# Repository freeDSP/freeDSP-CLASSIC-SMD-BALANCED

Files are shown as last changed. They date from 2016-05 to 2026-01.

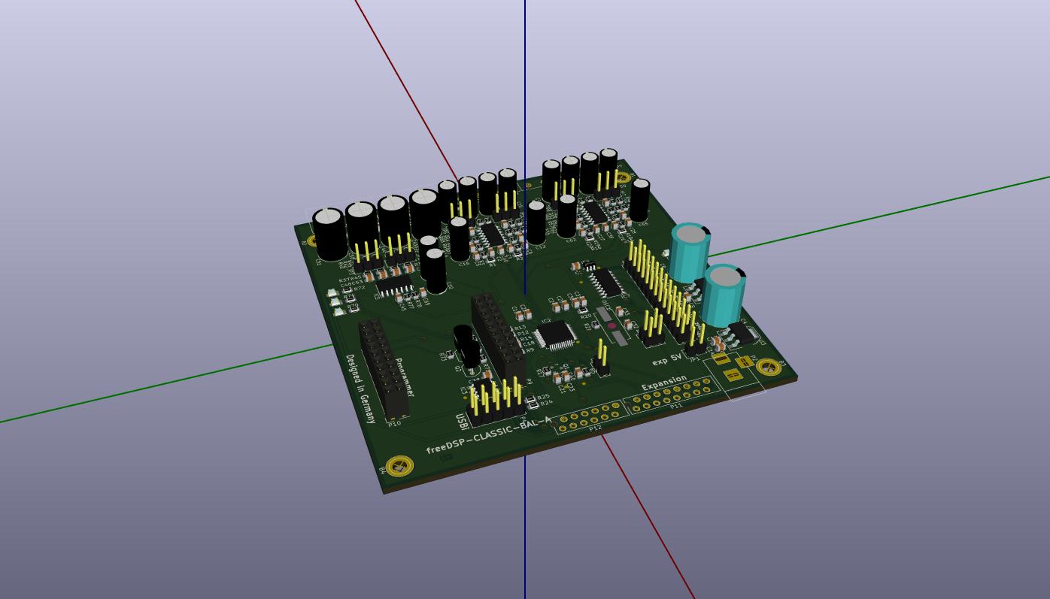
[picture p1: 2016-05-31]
DOCUMENTATION/PICTURES/rendering_betaversion.jpg

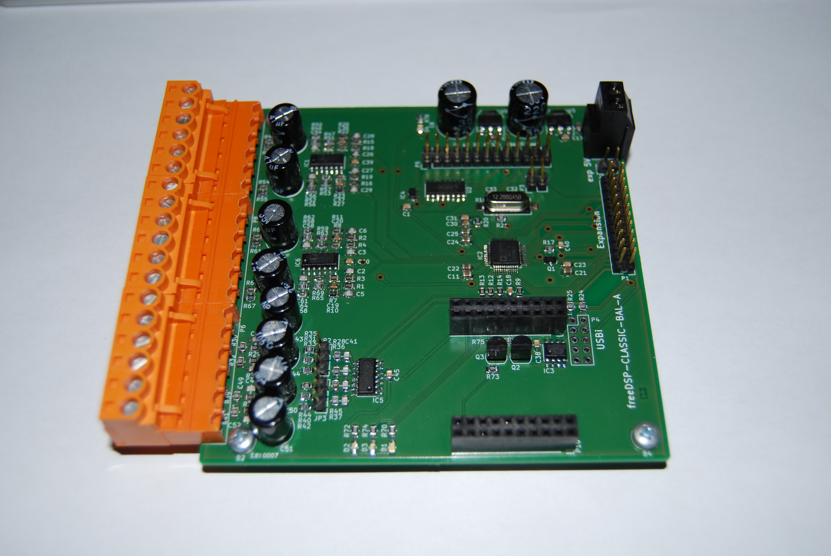
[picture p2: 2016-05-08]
DOCUMENTATION/PICTURES/DSC_0358.JPG

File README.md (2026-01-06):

# freeDSP-CLASSIC-SMD-BALANCED 
SMD Version with 1 I2S expansion header and balanced inputs/outputs and freeUSBi onboard.

## Upgrades from CLASSIC SMD A
- balanced audio inputs and outputs
- supports balanced interconnections with +6dBu (ARD nominal signal level)
- supports unbalanced interconnections with -10dBV (consumer audio nominal signal level)
- OpAmps supplied with +5V
- DC power input on barrel jack
- 1 standard I2S expansion header

For more information, please refer to the website [freedsp.github.io](https://freedsp.github.io/) and the documentation.  

## Status
Ready

## License

This work and all other materials under https://github.com/freeDSP are licensed under a <a rel="license" href="http://creativecommons.org/licenses/by-sa/4.0/legalcode">Creative Commons Attribution Share-Alike 4.0 license</a>. This allows for both personal and commercial derivative works, as long as they credit freeDSP and release their designs under the same license.

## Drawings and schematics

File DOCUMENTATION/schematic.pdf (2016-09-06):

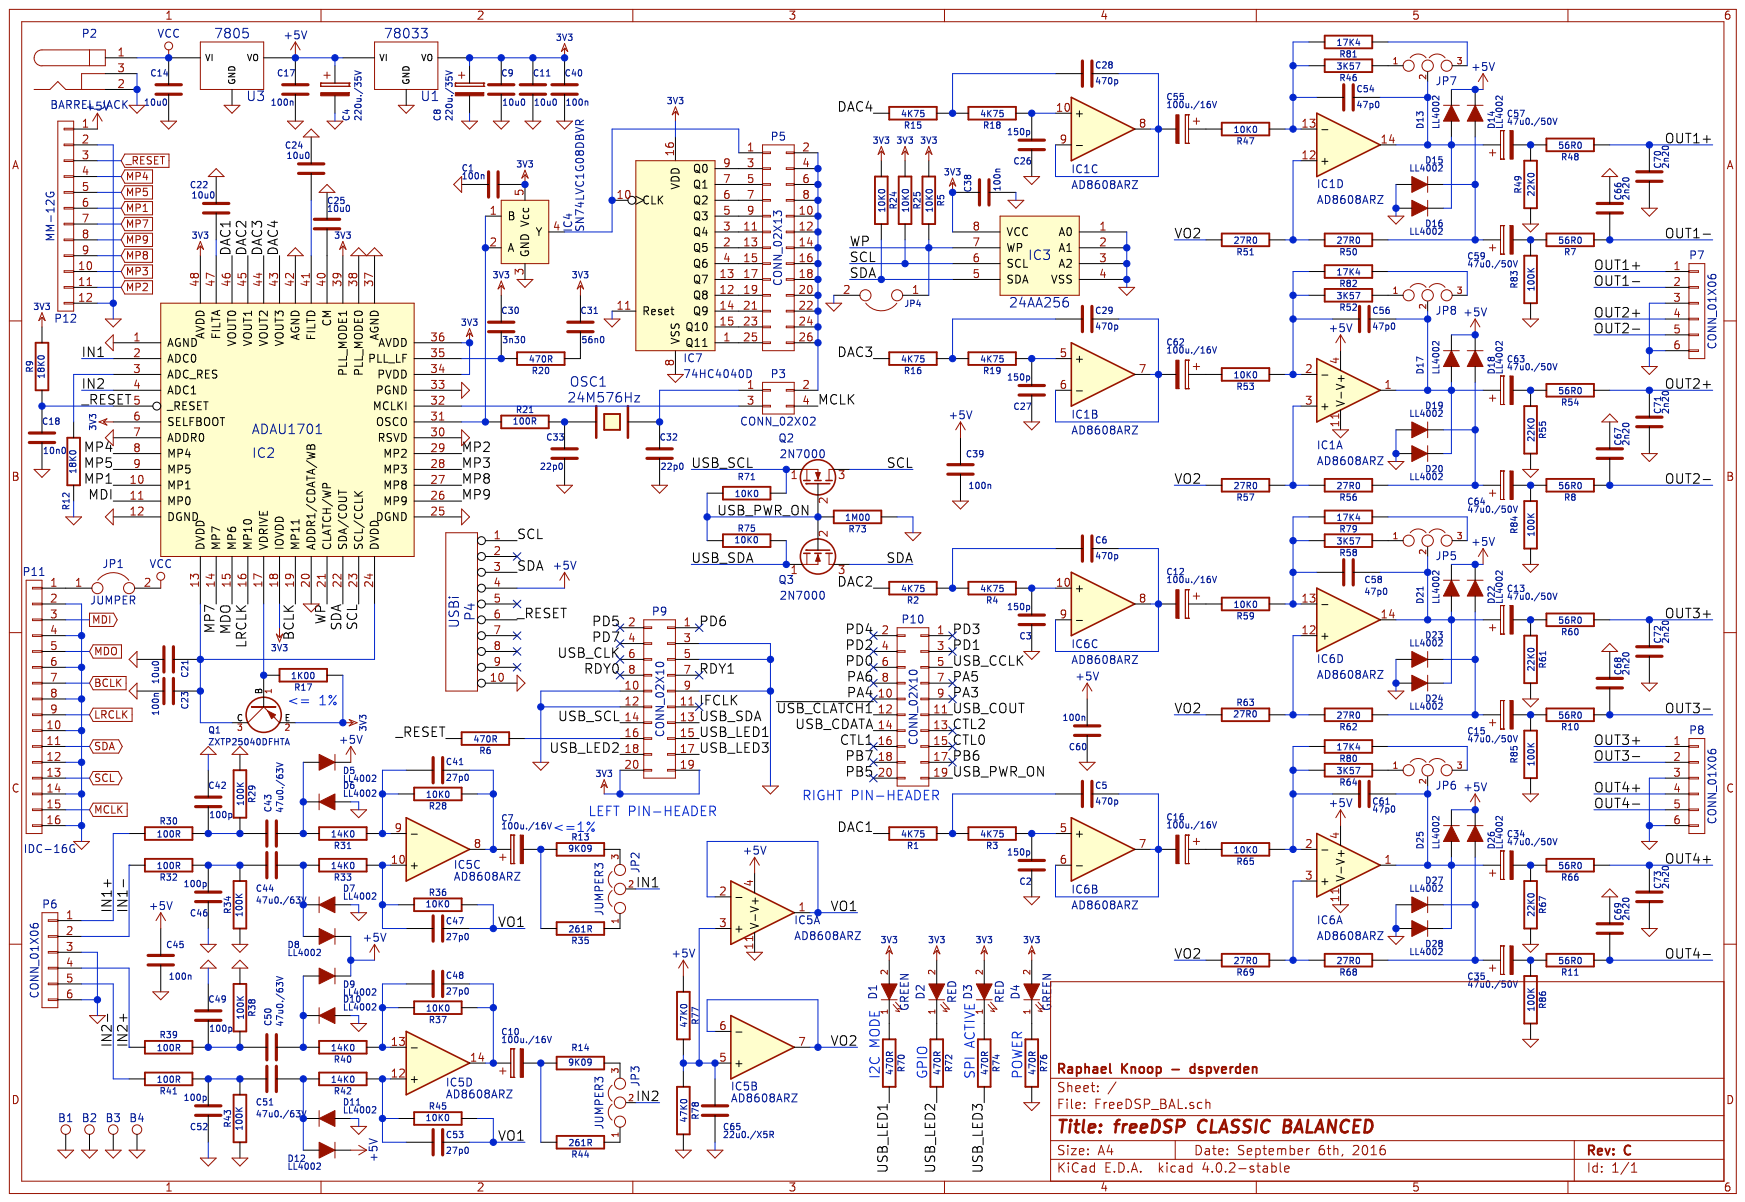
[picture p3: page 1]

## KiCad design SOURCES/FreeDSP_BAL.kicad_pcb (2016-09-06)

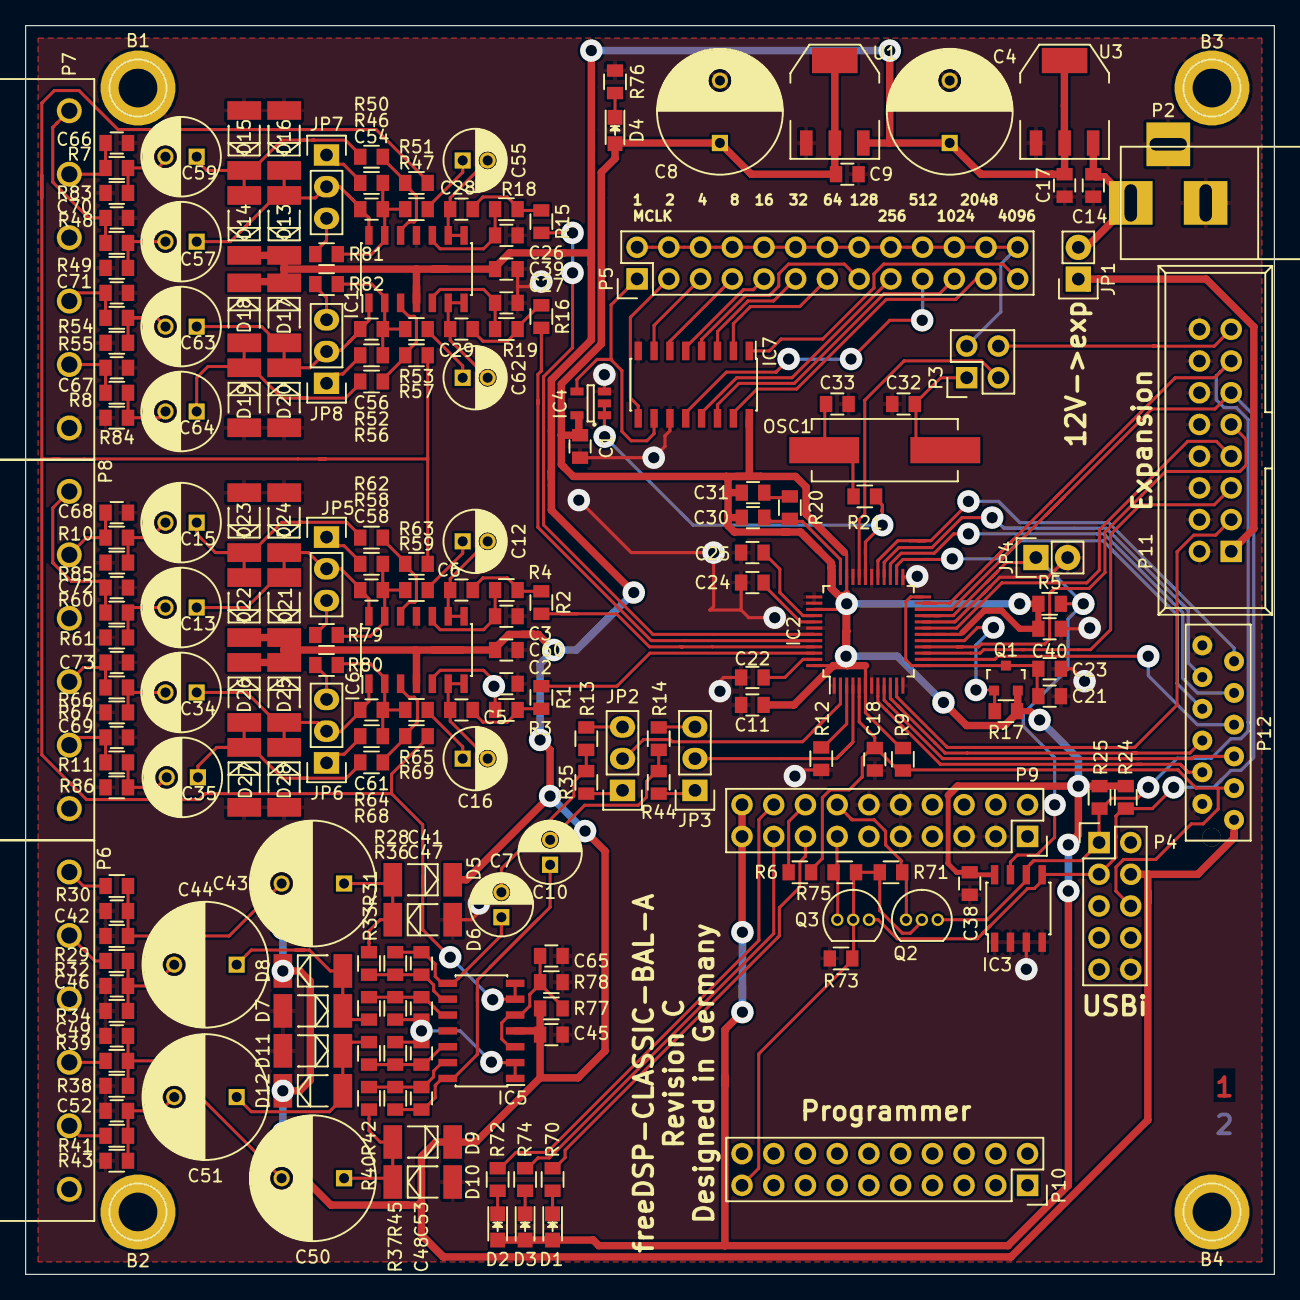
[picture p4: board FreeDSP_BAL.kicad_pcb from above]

Board: 2 copper layers, 100.0 x 100.0 mm, 215 parts (0 on the bottom side), 148 nets.

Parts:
B1, B2, B3, B4: TEST_1P; 1pin
C1, C17, C23, C38, C39, C40, C45, C60: 100n; C0805-X7R
C2, C3, C26, C27: 150p; C0805-X7R
C4, C8: 220u./35V; C_Radial_D10_L13_P5
C5, C6, C28, C29: 470p; C0805-X7R
C7, C10, C12, C16, C55, C62: 100u./16V; C_Radial_D5_L11_P2
C9, C11, C14, C21, C22, C24, C25: 10u0; C0805-X7R
C13, C15, C34, C35, C57, C59, C63, C64: 47u0./50V; C_Radial_D6.3_L11.2_P2.5
C18: 10n0; C0805-X7R
C30: 3n30; C0805-X7R
C31: 56n0; C0805-X7R
C32, C33: 22p0; C0805-X7R
C41, C47, C48, C53: 27p0; C0805-X7R
C42, C46, C49, C52: 100p; C0805-X7R
C43, C44, C50, C51: 47u0./63V; C_Radial_D10_L16_P5
C54, C56, C58, C61: 47p0; C0805-X7R
C65: 22u0./X5R; C0805-X7R
C66, C67, C68, C69, C70, C71, C72, C73: 2n20; C0805-X7R
D1, D4: GREEN; LED_0805
D2, D3: RED; LED_0805
D5, D6, D7, D8, D9, D10, D11, D12, D13, D14, D15, D16, D17, D18, D19, D20, D21, D22, D23, D24, D25, D26, D27, D28: LL4002; MELF_Standard
IC1, IC5, IC6: AD8608ARZ; SOIC-14_3.9x8.7mm_Pitch1.27mm
IC2: ADAU1701; LQFP-48_7x7mm_Pitch0.5mm
IC3: 24AA256; SOIC-8_3.9x4.9mm_Pitch1.27mm
IC4: SN74LVC1G08DBVR; SOT-23-5
IC7: 74HC4040D; SOIC-16_3.9x9.9mm_Pitch1.27mm
JP1, JP4: JUMPER; Pin_Header_Straight_1x02
JP2, JP3, JP5, JP6, JP7, JP8: JUMPER3; Pin_Header_Straight_1x03
OSC1: 24M576Hz; Crystal_HC49-SD_SMD
P2: BARREL_JACK
P3: CONN_02X02; Pin_Header_Straight_2x02
P4: USBi; Pin_Header_Straight_2x05
P5: CONN_02X13; Pin_Header_Straight_2x13
P6, P7, P8: CONN_01X06; SL_5.08HC-06-90
P9, P10: CONN_02X10; Socket_Strip_Straight_2x10
P11: IDC-16G; IDC_Header_Straight_16pins
P12: MM-12G
Q1: ZXTP25040DFHTA; SOT-23
Q2, Q3: 2N7000; TO-92_Inline_Narrow_Oval
R1, R2, R3, R4, R15, R16, R18, R19: 4K75; C0805-RES
R5, R24, R25, R28, R36, R37, R45, R47, R53, R59, R65, R71, R75: 10K0; C0805-RES
R6, R20, R70, R72, R74, R76: 470R; C0805-RES
R7, R8, R10, R11, R48, R54, R60, R66: 56R0; C0805-RES
R9, R12: 18K0; C0805-RES
R13, R14: 9K09; C0805-RES
R17: 1K00; C0805-RES
R21, R30, R32, R39, R41: 100R; C0805-RES
R29, R34, R38, R43, R83, R84, R85, R86: 100K; C0805-RES
R31, R33, R40, R42: 14K0; C0805-RES
R35, R44: 261R; C0805-RES
R46, R52, R58, R64: 3K57; C0805-RES
R49, R55, R61, R67: 22K0; C0805-RES
R50, R51, R56, R57, R62, R63, R68, R69: 27R0; C0805-RES
R73: 1M00; C0805-RES
R77, R78: 47K0; C0805-RES
R79, R80, R81, R82: 17K4; C0805-RES
U1: 78033; SOT-223_Reg_MAE
U3: 7805; SOT-223_Reg_MAE

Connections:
3V3: C1.1, C8.1, C9.1, C11.1, C30.1, C31.1, C38.1, C40.1, D1.2, D2.2, D3.2, D4.2, IC2.6, IC2.18, IC2.34, IC2.36, IC2.39, IC2.48, IC3.8, IC4.5, IC7.16, P9.19, P9.20, Q1.2, R5.2, R9.2, R17.2, R24.2, R25.2, U1.VO
+5V: C4.1, C17.1, C39.2, C45.2, C60.2, D5.1, D8.1, D9.1, D12.1, D13.1, D14.1, D17.1, D18.1, D21.1, D22.1, D25.1, D26.1, IC1.4, IC5.4, IC6.4, P4.4, P12.1, R77.1, U1.VI, U3.VO
/DAC1: IC2.46, R1.2
/DAC2: IC2.45, R2.2
/DAC3: IC2.44, R16.2
/DAC4: IC2.43, R15.2
/IN1: IC2.2, JP2.2
/IN1+: P6.1, R30.2
/IN1-: P6.2, R32.2
/IN2: IC2.4, JP3.2
/IN2+: P6.4, R39.2
/IN2-: P6.5, R41.2
/OUT1+: C70.2, P7.1, R48.1
/OUT1-: C66.1, P7.2, R7.1
/OUT2+: C71.2, P7.4, R54.1
/OUT2-: C67.1, P7.5, R8.1
/OUT3+: C72.2, P8.1, R60.1
/OUT3-: C68.1, P8.2, R10.1
/OUT4+: C73.2, P8.4, R66.1
/OUT4-: C69.1, P8.5, R11.1
/USB_LED1: P9.15, R70.2
/USB_LED2: P9.18, R72.2
/USB_LED3: P9.17, R74.2
/USB_PWR_ON: P10.19, Q2.2, Q3.2, R71.2, R73.2, R75.1
/USB_SCL: P9.14, Q2.1, R71.1
/USB_SDA: P9.13, Q3.1, R75.2
/VO1: C47.2, C53.2, IC5.1, IC5.2, R36.2, R45.2
/VO2: IC5.6, IC5.7, R51.2, R57.2, R63.1, R69.2
/WP: IC2.21, IC3.7, JP4.1, R5.1
BCLK: IC2.19, P11.7
GND: B1.1, B2.1, B3.1, B4.1, C1.2, C2.1, C3.1, C4.2, C8.2, C9.2, C11.2, C14.2, C17.2, C18.2, C21.2, C22.2, C23.2, C24.2, C25.2, C26.1, C27.1, C32.2, C33.2, C38.2, C39.1, C40.2, C42.1, C45.1, C46.1, C49.1, C52.1, C60.1, C65.1, C66.2, C67.2, C68.2, C69.2, C70.1, C71.1, C72.1, C73.1, D6.2, D7.2, D10.2, D11.2, D15.2, D16.2, D19.2, D20.2, D23.2, D24.2, D27.2, D28.2, IC1.11, IC2.1, IC2.7, IC2.12, IC2.20, IC2.25, IC2.30, IC2.33, IC2.37, IC2.38, IC2.42, IC3.1, IC3.2, IC3.3, IC3.4, IC4.3, IC5.11, IC6.11, IC7.8, IC7.11, JP4.2, P2.2, P2.3, P4.10, P6.3, P6.6, P7.3, P7.6, P8.3, P8.6, P9.3, P9.5, P9.9, P9.10, P9.12, P11.2, P11.4, P11.6, P11.8, P11.10, P11.12, P11.14, P11.16, P12.2, P12.12, R12.1, R29.1, R34.1, R38.1, R43.1, R49.2, R55.2, R61.2, R67.2, R73.1, R76.2, R78.2, R83.2, R84.2, R85.2, R86.2, U1.GND, U3.GND
LRCLK: IC2.16, P11.9
MCLK: P3.4, P11.15
MDI: IC2.11, P11.3
MDO: IC2.15, P11.5
MP1: IC2.10, P12.6
MP2: IC2.29, P12.11
MP3: IC2.28, P12.10
MP4: IC2.8, P12.4
MP5: IC2.9, P12.5
MP7: IC2.14, P12.7
MP8: IC2.27, P12.9
MP9: IC2.26, P12.8
unnamed: C2.2, IC6.5, R3.1
unnamed: C3.2, IC6.10, R4.1
unnamed: C5.2, R1.1, R3.2
unnamed: C6.2, R2.1, R4.2
unnamed: C7.2, R13.1, R35.2
unnamed: C10.1, C48.1, IC5.14, R37.1
unnamed: C10.2, R14.1, R44.2
unnamed: C12.1, R59.2
unnamed: C6.1, C12.2, IC6.8, IC6.9
unnamed: C13.1, C58.1, D21.2, D24.1, IC6.14, JP5.2
unnamed: C13.2, R60.2, R61.1
unnamed: C15.1, D22.2, D23.1, R62.1
unnamed: C15.2, R10.2, R85.1
unnamed: C16.1, R65.2
unnamed: C5.1, C16.2, IC6.6, IC6.7
unnamed: C21.1, C23.1, IC2.13, IC2.24, Q1.3
unnamed: C22.1, IC2.47
unnamed: C24.1, IC2.41
unnamed: C25.1, IC2.40
unnamed: C26.2, IC1.10, R18.1
unnamed: C27.2, IC1.5, R19.1
unnamed: C28.1, C55.2, IC1.8, IC1.9
unnamed: C28.2, R15.1, R18.2
unnamed: C29.1, C62.2, IC1.6, IC1.7
unnamed: C29.2, R16.1, R19.2
unnamed: C30.2, IC2.35, R20.2
unnamed: C31.2, R20.1
unnamed: C32.1, OSC1.2, P3.1
unnamed: C33.1, OSC1.1, R21.2
unnamed: C34.1, C61.1, D25.2, D28.1, IC6.1, JP6.2
unnamed: C34.2, R66.2, R67.1
unnamed: C35.1, D26.2, D27.1, R68.1
unnamed: C35.2, R11.2, R86.1
unnamed: C7.1, C41.1, IC5.8, R28.1
unnamed: C41.2, IC5.9, R28.2, R31.1
unnamed: C42.2, C43.2, R29.2, R30.1
unnamed: C43.1, D5.2, D6.1, R31.2
unnamed: C44.1, D7.1, D8.2, R33.2
unnamed: C44.2, C46.2, R32.1, R34.2
unnamed: C47.1, IC5.10, R33.1, R36.1
unnamed: C48.2, IC5.13, R37.2, R40.1
unnamed: C49.2, C50.2, R38.2, R39.1
unnamed: C50.1, D9.2, D10.1, R40.2
unnamed: C51.1, D11.1, D12.2, R42.2
unnamed: C51.2, C52.2, R41.1, R43.2
unnamed: C53.1, IC5.12, R42.1, R45.1
unnamed: C54.1, C57.1, D13.2, D16.1, IC1.14, JP7.2
unnamed: C54.2, IC1.13, R46.2, R47.1, R81.2
unnamed: C55.1, R47.2
unnamed: C56.1, C63.1, D17.2, D20.1, IC1.1, JP8.2
unnamed: C56.2, IC1.2, R52.2, R53.1, R82.2
unnamed: C57.2, R48.2, R49.1
unnamed: C58.2, IC6.13, R58.2, R59.1, R79.2
unnamed: C59.1, D14.2, D15.1, R50.1
unnamed: C59.2, R7.2, R83.1
unnamed: C61.2, IC6.2, R64.2, R65.1, R80.2
unnamed: C62.1, R53.2
unnamed: C63.2, R54.2, R55.1
unnamed: C64.1, D18.2, D19.1, R56.1
unnamed: C64.2, R8.2, R84.1
unnamed: C65.2, IC5.3, IC5.5, R77.2, R78.1
unnamed: D1.1, R70.1
unnamed: D2.1, R72.1
unnamed: D3.1, R74.1
unnamed: D4.1, R76.1
unnamed: IC1.3, R56.2, R57.1
unnamed: IC1.12, R50.2, R51.1
unnamed: IC2.3, R12.2
unnamed: IC2.17, Q1.1, R17.1
unnamed: IC2.31, IC4.1, IC4.2, R21.1
unnamed: IC2.32, P3.3
unnamed: IC4.4, IC7.10, P5.1
unnamed: IC6.3, R68.2, R69.1
unnamed: IC6.12, R62.2, R63.2
unnamed: IC7.1, P5.25
unnamed: IC7.2, P5.13
unnamed: IC7.3, P5.11
unnamed: IC7.4, P5.15
unnamed: IC7.5, P5.9
unnamed: IC7.6, P5.7
unnamed: IC7.7, P5.5
unnamed: IC7.9, P5.3
unnamed: IC7.12, P5.19
unnamed: IC7.13, P5.17
unnamed: IC7.14, P5.21
unnamed: IC7.15, P5.23
unnamed: JP1.1, P11.1
unnamed: JP2.1, R35.1
unnamed: JP2.3, R13.2
unnamed: JP3.1, R44.1
unnamed: JP3.3, R14.2
unnamed: JP5.1, R58.1
unnamed: JP5.3, R79.1
unnamed: JP6.1, R64.1
unnamed: JP6.3, R80.1
unnamed: JP7.1, R46.1
unnamed: JP7.3, R81.1
unnamed: JP8.1, R52.1
unnamed: JP8.3, R82.1
unnamed: P3.2, P5.2, P5.4, P5.6, P5.8, P5.10, P5.12, P5.14, P5.16, P5.18, P5.20, P5.22, P5.24, P5.26
unnamed: P9.16, R6.1
SCL: IC2.23, IC3.6, P4.1, P11.13, Q2.3, R25.1
SDA: IC2.22, IC3.5, P4.3, P11.11, Q3.3, R24.1
VCC: C14.1, JP1.2, P2.1, U3.VI
_RESET: C18.1, IC2.5, P4.6, P12.3, R6.2, R9.1

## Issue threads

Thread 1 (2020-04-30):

PCB Updated with 3d packages

mbt28, 2020-04-30:
Hi,

I updated the pcb with built-in 3d packages of KiCAD. All the units have their 3d shapes beside P2 Power Barrel Jack and P12. You can find the rendered images below. If you are interested in to update the github source I can share the files.

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

Have a nice day

BasssT, 2020-05-04:
Very nice. Thanks. I give you rights to update the repo if you like.

Closed 2020-05-04.

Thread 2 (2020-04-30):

Full SMD packages

mbt28, 2020-04-30:
Hi,

I am not audio expert thats why I am asking, are there any reason that you are using some of the caps are tht? If it is possible we can order the whole pcb prototype from cheap manufacturers.

If yes I will try to find smd compenent parts for replacement.

Thanks

BasssT, 2020-05-04:
You can replace everything with smd components if available. Please share if you found a producer. Thanks.

mbt28, 2020-05-06:
Hi,

I started to replace some of the TH parts already however the capacitors: C43, C44, C50, C51 seems like to have value 47u0./63V, does it mean 47uf 6.3V or 63V?

Thanks

dspverden, 2020-05-06:
Hi,

the caps are tht because I had them in stock. They are rated at 63V.  You can replace them by e.g. 25V. Please make sure that you use bipolar electrolytic caps or orient the caps in the right way: There is positive voltage offset on the opamp side.

Raphael

mbt28, 2020-05-07:
Hi Again,

Finally I replaced all the components(beside connectors) with the SMD ones but I need to fix the routes as well. What kind of connector is P12? Do you have any link to the datasheet? I cannot find a similar connector in KiCAD.

Thanks

So far looks like something this:
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

dspverden, 2020-05-10:
P12 is a MicroMatch from TE. You can easily find the 3D model for it.[https://www.te.com/deu-de/product-8-215079-2.html](url)

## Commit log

2016-05-08 Picture of prototype.
2016-05-12 Cleaned BOM (footprints).
    [FreeDSP_SMD.kicad_pcb, FreeDSP_SMD.sch]
2016-05-17 - Added 10K PullUp and GND-Jumper on WP-line - Fixed footprint of Q1
    [FreeDSP_SMD.kicad_pcb, FreeDSP_SMD.sch]
2016-05-19 - Bugfix ADC-Stage: Applied VCC/2 - Changed VCC of OpAmps to +5V - Changed gains, Pro: +6dBu (ARD-Norm) and Con: -10dBv for full scale
    [FreeDSP_SMD.kicad_pcb, FreeDSP_SMD.sch]
2016-05-20 Bugfix DAC-Stage: Applied VCC/2 - Supplied OpAmps with +5V - Reworked gain settings: Pro +6dBu, Consumer -10dBV
    [FreeDSP_SMD.kicad_pcb, FreeDSP_SMD.sch]
2016-05-21 Changed DC supply connector to barrel jack
    [FreeDSP_SMD.kicad_pcb, FreeDSP_SMD.sch]
2016-05-23 Moved EZ-USB sockets => EZ-USB now fits into standard enclosure.
    [FreeDSP_SMD.kicad_pcb]
2016-05-24 Changed expansion header to new standard i2s expansion header
    [FreeDSP_SMD.kicad_pcb, FreeDSP_SMD.sch]
2016-05-24 WB on GND
    [FreeDSP_SMD.kicad_pcb, FreeDSP_SMD.sch]
2016-05-29 Updated Gerber and BOM
    [FreeDSP_BAL.kicad_pcb, FreeDSP_BAL.sch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]
2016-05-31 Added 3D rendering of beta-Ready version.
    [FreeDSP_BAL.kicad_pcb]
2016-07-14 Correction of some typos
    [FreeDSP_BAL.kicad_pcb, FreeDSP_BAL.sch]
2016-07-14 Chaged OSC1 to 24.576MHz
    [FreeDSP_BAL.sch]
2016-08-30 Changed voltage divider for outputs to avoid clipping for full scale (ADAU1701 on prototype gives 2.8Vpp instead of 2.5Vpp)
    [FreeDSP_BAL.sch]
2016-08-30 Changed expansion header to 2.54 IDC
    [FreeDSP_BAL.kicad_pcb, FreeDSP_BAL.sch]
2016-08-30 Updated Gerbers
    [1-FreeDSP_BAL-TopSilkscreen.gbr, 2-FreeDSP_BAL-TopSoldermask.gbr, 3-FreeDSP_BAL-TopLayer.gbr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]
2016-09-06 Revision C: Improvement of input and output stages. Added some fault protection.
    [FreeDSP_BAL.kicad_pcb, FreeDSP_BAL.sch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]
